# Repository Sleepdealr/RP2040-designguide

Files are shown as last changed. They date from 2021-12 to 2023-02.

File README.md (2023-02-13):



# Hardware design for the RP2040

This guide requires you to have prerequisite knowledge about PCB design and a little about the RP2040. This is not a guide for absolute beginners and should not be treated as one.

I have multiple tested and working boards using the RP2040, including an open source one you can find [here](https://github.com/Sleepdealr/RPAD)!

Bit of a disclaimer: I have mostly switched from RP2040 over to STM32F072 due to a few reasons. Mostly component cost and the amount of parts necessary, as well as overall stability. I have a tested and OSH f072 PCBs available on github. Namely [here](https://github.com/Sleepdealr/Majestouch-2-TKL-Replacement-Controller), [here](https://github.com/Sleepdealr/OSFRL), and [here](https://github.com/Sleepdealr/Kingsaver-Replacement-PCB). Designing with f072 is generally easier as well, so I would suggest it even for beginners.

## Contents

- [Hardware design for the RP2040](#hardware-design-for-the-rp2040)
  - [Contents](#contents)
  - [KiCad Version](#kicad-version)
  - [Libraries](#libraries)
  - [Extra Resources](#extra-resources)
  - [Schematic](#schematic)
    - [Component Choices](#component-choices)
      - [Voltage Regulator](#voltage-regulator)
      - [Crystal](#crystal)
      - [Flash](#flash)
      - [Pushbuttons](#pushbuttons)
  - [PCB](#pcb)
    - [Placement / Routing](#placement--routing)
    - [BOM](#bom)
  - [Firmware](#firmware)
    - [Flashing QMK on Linux from CLI](#flashing-qmk-on-linux-from-cli)
  - [Extra info](#extra-info)
    - [EEPROM](#eeprom)
  - [Too Complicated?](#too-complicated)

## KiCad Version

To open these files, you will need a recent stable version of KiCad (6.0 or later).

Stop using KiCad 5.X, it's out of date

## Libraries

You can either import them into your own library or keep them separate.

- Symbol:
  - Created by me to be easier to use
  - `/PCB/Libraries/Sleep-lib`
- Footprint:
  - Taken from Raspberry
  - `/PCB/Libraries/Footprints/RP2040-QFN-56.kicad_mod`
  - 3D Model is included

Images of the 3DView, EEschema, and PCBNew in the `/img` folder.

## Extra Resources

All the other information I found about the chip is in in the `/Pico-Resources` Folder

## Schematic

[PDF of schematic](PCB/RP2040-Guide.pdf)

THIS IMAGE WILL BE OUT OF DATE. LOOK AT THE PDF FOR THE LATEST VERSION.
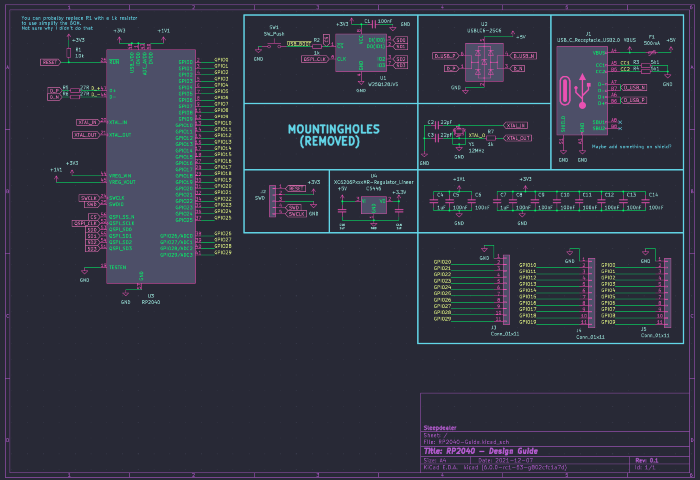
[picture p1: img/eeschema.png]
Schematic


If you want to know more about the components choices, read the section below or Raspberry's hardware design example.
The PDF is `/Pico-Resources/hardware-design-with-rp2040.pdf`.

I would also recommend reading my [Best practices for PCB Design](https://gist.github.com/Sleepdealr/ab05f5edb82eae9e0393f4d63da55adf) guide before making your own schematic or PCB

Breakout for SWD/GPIO is NOT required.

### Component Choices

Trust me on these pls

#### Voltage Regulator

Use the XC6206, it's a basic part on JLC. The 200mA it provides is plenty for the RP2040.

The AMS1117 has high quiescent current, needs large caps, and has a bad minimum load. Don't use it.

#### Crystal

C9002 is a great basic part for a 12MHz 3225 crystal

#### Flash

There are a ton of options for flash, but I tend to stick with C82317 as it's a basic part and has a good price. More than enough flash for any keyboard.

#### Pushbuttons

Although I didn't use a button on the included PCB files, you can easily add one yourself. A good cheap button that fits the Alps SKQG footprint is C318884.

####

## PCB

THIS IMAGE WILL BE OUT OF DATE. LOOK AT THE KiCad FILES FOR THE LATEST VERSION.
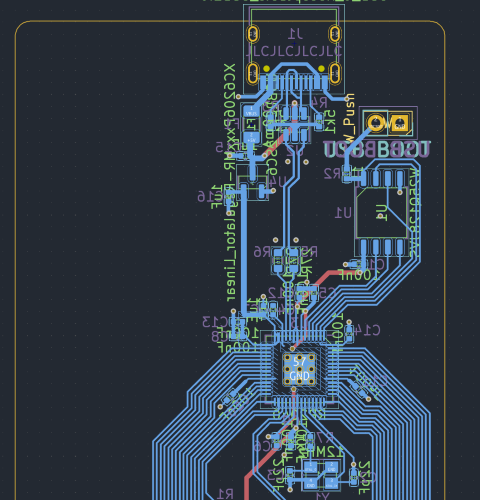
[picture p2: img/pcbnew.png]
PCB


### Placement / Routing

- Fills inside of the MCU were taken from the design example. You can just copy paste them out. Make sure to set the correct zone priority and clearances. Zones are filled from high to low numbers.
- Keep the decoupling capacitors close to their respective pins.
- Keep the flash and crystal as close as possible to the MCU with minimal overlaps and vias
  - If anything, just copy paste from my files
- I would suggest including an actual switch for USB BOOT or RESET on to make it easier to flash, but that's up to you.

### BOM

- Everything on the PCB can be assembled by JLC, all the part numbers have been added to the components with the Kicad JLCPCB plugin
- I have tested and working JLC part numbers for all of the components, but check the stock levels and prices first before ordering. There may be a better alternative available
- There are a few different flash sizes and packages to choose from. All of them should work pretty much the same, since firmware size is not an issue. I usually just go with the cheapest option

## Firmware

Both QMK and Vial have support for RP2040 in their master branches. Make sure to check the features you want before designing

- QMK
  - QMK Main Branch: <https://github.com/qmk/qmk_firmware/>
  - RP2040 available features: <https://docs.qmk.fm/#/platformdev_rp2040?id=raspberry-pi-rp2040>
- Vial
  - Vial Main Branch: <https://github.com/vial-kb/vial-qmk/>
- KMK
  - <https://github.com/KMKfw/kmk_firmware>
- Keyberon
  - <https://github.com/TeXitoi/keyberon>

To flash, hold the USB-BOOT button down as you plug in the keyboard (like Bootmagic reset)

### Flashing QMK on Linux from CLI

You will need to install picotool with your distro's package manager of choice, or [build it manually](https://github.com/raspberrypi/picotool#building).

In order to be able to flash properly, you will need to configure a custom udev rule.

Open a terminal and execute this script.

```bash
sudo mkdir -p /etc/udev/rules.d/
echo '# /etc/udev/rules.d/99-pico.rules

# Make an RP2040 in BOOTSEL mode writable by all users, so you can `picotool`
# without `sudo`.
SUBSYSTEM=="usb", ATTRS{idVendor}=="2e8a", ATTRS{idProduct}=="0003", MODE="0666"

# Symlink an RP2040 running MicroPython from /dev/pico.
#
# Then you can `mpr connect $(realpath /dev/pico)`.
SUBSYSTEM=="tty", ATTRS{idVendor}=="2e8a", ATTRS{idProduct}=="0005", SYMLINK+="pico"", TAG+="uaccess", TAG+="udev-acl"' | sudo tee /etc/udev/rules.d/99-pico.rules
sudo udevadm control --reload-rules
sudo udevadm trigger
```

Command borrowed from xyz's VIAL docs

## Extra info

### EEPROM

While the Raspberry Pi Pico RP2040 does not come with an EEPROM onboard, we simulate one by using a single 4K chunk of flash at the end of flash space.

**Note that this is a simulated EEPROM and will only support the number of writes as the onboard flash chip, not the 100,000 or so of a real EEPROM.** Therefore, do not frequently update the EEPROM or you may prematurely wear out the flash.

Source: <https://arduino-pico.readthedocs.io/en/latest/eeprom.html>

This isn't really an issue, as the flash chip I used is rated for 100k cycles [link to datasheet](https://www.winbond.com/resource-files/w25q128jv_dtr%20revc%2003272018%20plus.pdf)

## Too Complicated?

If all of this seems too daunting, my commissions are open! You can contact me on discord at Sleepdealer#0001 or through email at sleepdealer01@protonmail.com

Portfolio: <https://sleepdealer.xyz/article/portfolio>

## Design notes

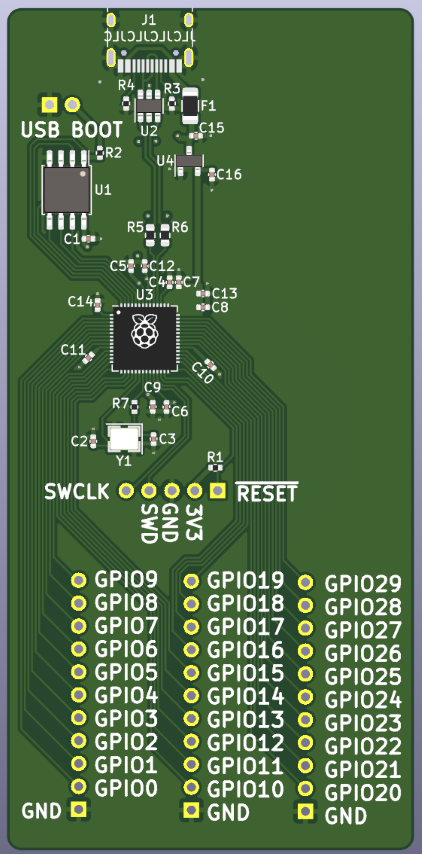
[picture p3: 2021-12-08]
img/render-board-back.png

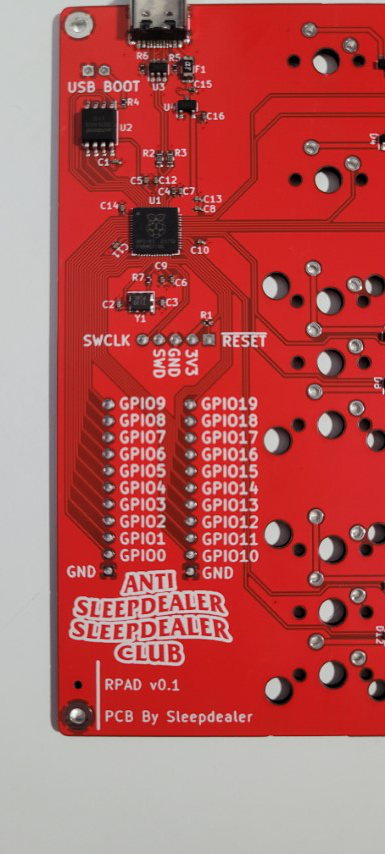
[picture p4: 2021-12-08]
img/RPAD.jpg

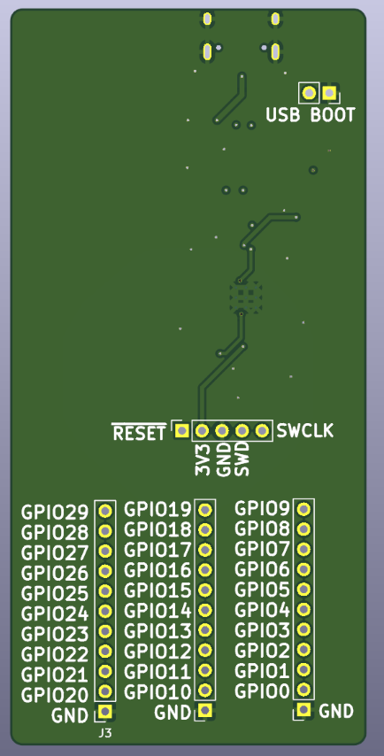
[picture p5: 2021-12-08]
img/render-board-front.png

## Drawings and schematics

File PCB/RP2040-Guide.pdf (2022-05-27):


1 GPIO8 11 GPIO9 12 GPIO10 13 GPIO11 14 GPIO12 15 GPIO13 16 GPIO14 17 GPIO15 18 TESTEN 19 GPIO0 2 XTAL_IN 20 XTAL_OUT 21 SWCLK 24 SWDIO 25 ~{RUN} 26 GPIO16 27 GPIO17 28 GPIO18 29 GPIO1 3 GPIO19 30 GPIO20 31 GPIO21 32 GPIO22 34 GPIO23 35 GPIO24 36 GPIO25 37 GPIO26/ADC0 38 GPIO27/ADC1 39 GPIO2 4 GPIO28/ADC2 40 GPIO29/ADC3 41 ADC_AVDD 43 VREG_VIN 44 VREG_VOUT 45 D- 46 D+ 47 USB_VDD 48 GPIO3 5 DVDD 50 QSPI_SD3 51 QSPI_SCLK 52 QSPI_SD0 53 QSPI_SD2 54 QSPI_SD1 55 QSPI_SS_N 56 GND 57 GPIO4 6 GPIO5 7 GPIO6 8 GPIO7 9 U3 GND RP2040 +3.3V C6

File: RP2040-Guide.kicad_sch Sheet: / Sleepdealer

Id: 1/1 Title: RP2040 - Design Guide

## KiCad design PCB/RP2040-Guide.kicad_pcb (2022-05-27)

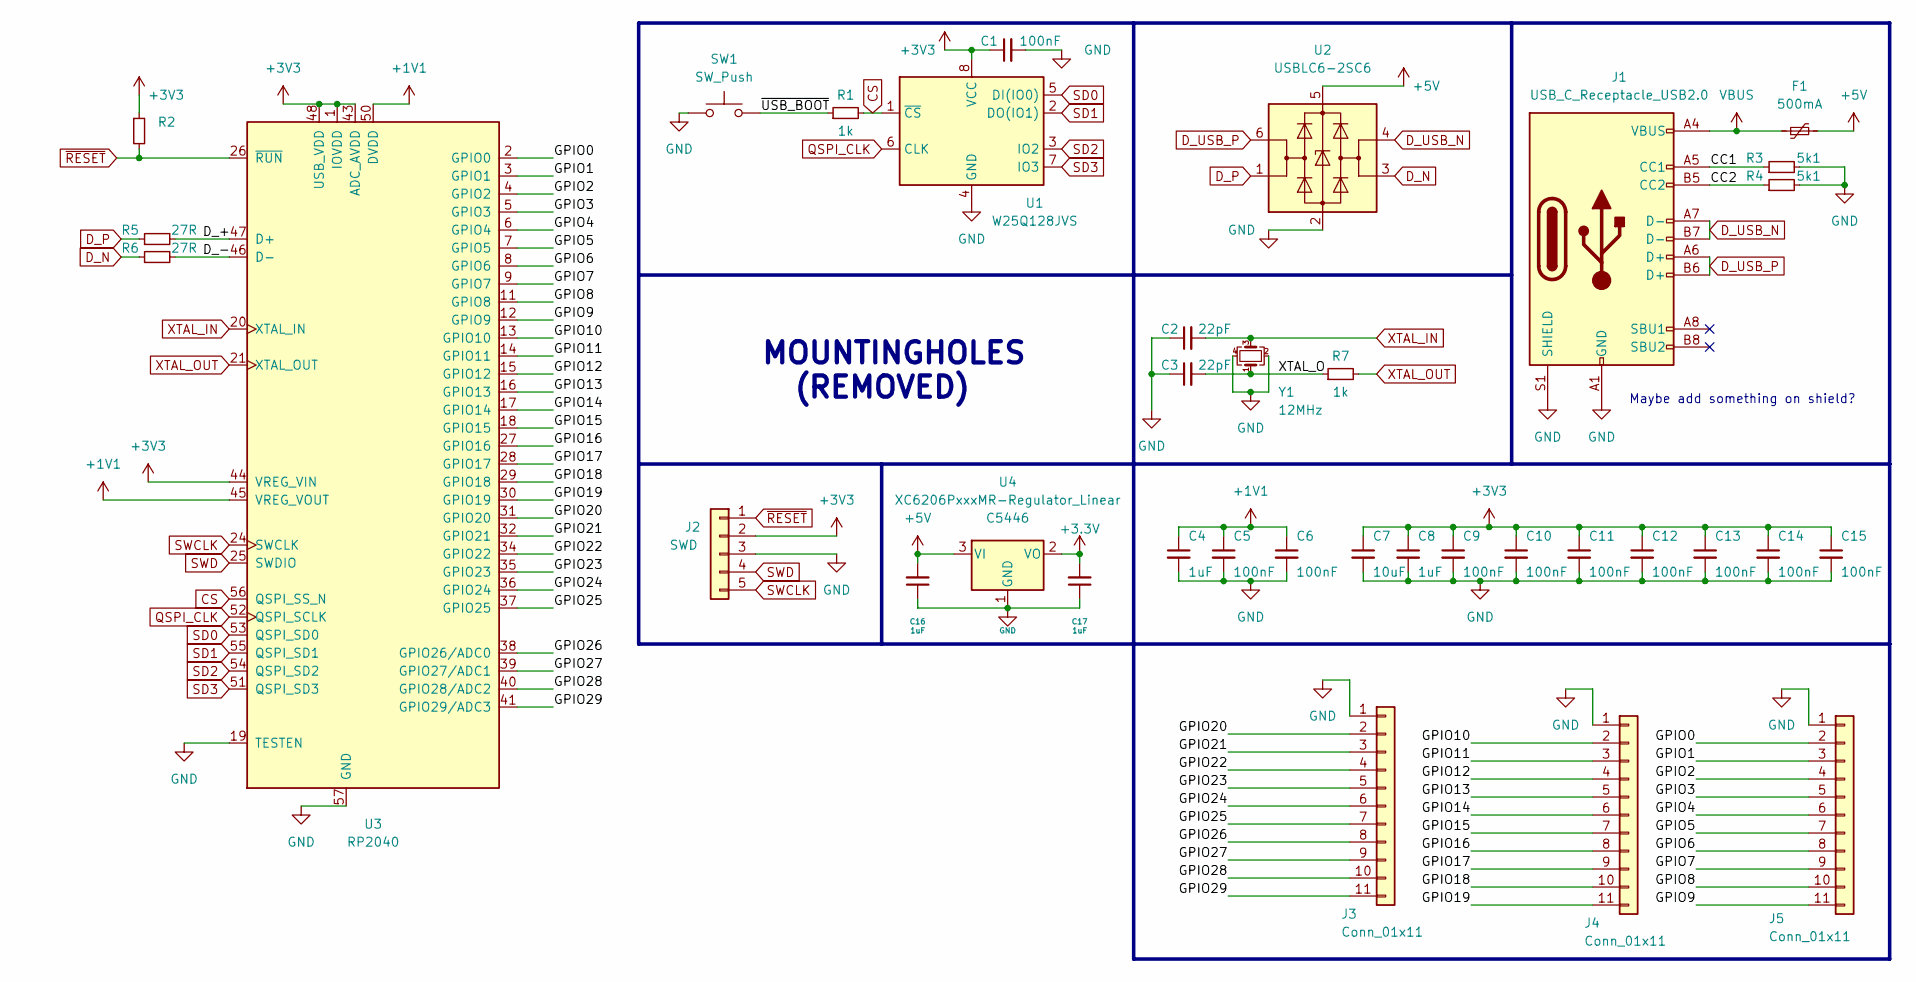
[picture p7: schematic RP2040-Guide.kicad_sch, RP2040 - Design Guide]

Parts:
C1, C5, C6, C9, C10, C11, C12, C13, C14, C15: 100nF; C_0402_1005Metric; LCSC C1525
C2, C3: 22pF; C_0402_1005Metric; LCSC C1555
C4, C8, C16, C17: 1uF; C_0402_1005Metric; LCSC C52923
C7: 10uF; C_0402_1005Metric; LCSC C15525
F1: 500mA; Fuse_1206_3216Metric; LCSC C70076
J1: USB_C_Receptacle_USB2.0; USB_C_Receptacle_HRO_TYPE-C-31-M-12; LCSC C165948
J2: SWD; PinSocket_1x05_P2.54mm_Vertical
J3, J4, J5: Conn_01x11; PinSocket_1x11_P2.54mm_Vertical
R1, R7: 1k; R_0402_1005Metric; LCSC C11702
R2: LCSC C11702
R3, R4: 5k1; R_0402_1005Metric; LCSC C25905
R5, R6: 27R; R_0603_1608Metric; LCSC C25190
SW1: SW_Push; PinSocket_1x02_P2.54mm_Vertical
U1: W25Q128JVS; SOIC-8_5.23x5.23mm_P1.27mm; LCSC C131025
U2: USBLC6-2SC6; SOT-23-6; LCSC C2827654
U3: RP2040; RP2040-QFN-56; LCSC C2040
U4: XC6206PxxxMR-Regulator_Linear; SOT-23; LCSC C5446
Y1: 12MHz; Crystal_SMD_3225-4Pin_3.2x2.5mm; LCSC C9002

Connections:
+1V1: C4.1, C5.1, C6.1, U3.23 (DVDD), U3.45 (VREG_VOUT), U3.50 (DVDD)
+5V: C16.2, F1.2, U2.5 (VBUS), U4.3 (VI)
/CC1: J1.A5 (CC1), R3.1
/CC2: J1.B5 (CC2), R4.1
/D_+: R5.2, U3.47 (D+)
/D_-: R6.2, U3.46 (D-)
/GPIO0: J5.2, U3.2 (GPIO0)
/GPIO1: J5.3, U3.3 (GPIO1)
/GPIO2: J5.4, U3.4 (GPIO2)
/GPIO3: J5.5, U3.5 (GPIO3)
/GPIO4: J5.6, U3.6 (GPIO4)
/GPIO5: J5.7, U3.7 (GPIO5)
/GPIO6: J5.8, U3.8 (GPIO6)
/GPIO7: J5.9, U3.9 (GPIO7)
/GPIO8: J5.10, U3.11 (GPIO8)
/GPIO9: J5.11, U3.12 (GPIO9)
/GPIO10: J4.2, U3.13 (GPIO10)
/GPIO11: J4.3, U3.14 (GPIO11)
/GPIO12: J4.4, U3.15 (GPIO12)
/GPIO13: J4.5, U3.16 (GPIO13)
/GPIO14: J4.6, U3.17 (GPIO14)
/GPIO15: J4.7, U3.18 (GPIO15)
/GPIO16: J4.8, U3.27 (GPIO16)
/GPIO17: J4.9, U3.28 (GPIO17)
/GPIO18: J4.10, U3.29 (GPIO18)
/GPIO19: J4.11, U3.30 (GPIO19)
/GPIO20: J3.2, U3.31 (GPIO20)
/GPIO21: J3.3, U3.32 (GPIO21)
/GPIO22: J3.4, U3.34 (GPIO22)
/GPIO23: J3.5, U3.35 (GPIO23)
/GPIO24: J3.6, U3.36 (GPIO24)
/GPIO25: J3.7, U3.37 (GPIO25)
/GPIO26: J3.8, U3.38 (GPIO26/ADC0)
/GPIO27: J3.9, U3.39 (GPIO27/ADC1)
/GPIO28: J3.10, U3.40 (GPIO28/ADC2)
/GPIO29: J3.11, U3.41 (GPIO29/ADC3)
/XTAL_O: C3.2, R7.1, Y1.1
/~USB_BOOT: R1.1, SW1.2
CS: R1.2, U1.1 (~CS), U3.56 (QSPI_SS_N)
D_N: R6.1, U2.3 (I/O2)
D_P: R5.1, U2.1 (I/O1)
D_USB_N: J1.A7 (D-), J1.B7 (D-), U2.4 (I/O2)
D_USB_P: J1.A6 (D+), J1.B6 (D+), U2.6 (I/O1)
GND: C1.2, C2.1, C3.1, C4.2, C5.2, C6.2, C7.2, C8.2, C9.2, C10.2, C11.2, C12.2, C13.2, C14.2, C15.2, C16.1, C17.1, J1.A1 (GND), J1.A12 (GND), J1.B1 (GND), J1.B12 (GND), J1.S1 (SHIELD), J2.3, J3.1, J4.1, J5.1, R3.2, R4.2, SW1.1, U1.4 (GND), U2.2 (GND), U3.19 (TESTEN), U3.57 (GND), U4.1 (GND), Y1.2, Y1.4
QSPI_CLK: U1.6 (CLK), U3.52 (QSPI_SCLK)
SD0: U1.5 (DI(IO0)), U3.53 (QSPI_SD0)
SD1: U1.2 (DO(IO1)), U3.55 (QSPI_SD1)
SD2: U1.3 (IO2), U3.54 (QSPI_SD2)
SD3: U1.7 (IO3), U3.51 (QSPI_SD3)
SWCLK: J2.5, U3.24 (SWCLK)
SWD: J2.4, U3.25 (SWDIO)
VBUS: F1.1, J1.A4 (VBUS), J1.A9 (VBUS), J1.B4 (VBUS), J1.B9 (VBUS)
XTAL_IN: C2.2, U3.20 (XTAL_IN), Y1.3
XTAL_OUT: R7.2, U3.21 (XTAL_OUT)
~RESET: J2.1, R2.2, U3.26 (~RUN)

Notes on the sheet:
MOUNTINGHOLES (REMOVED)
Maybe add something on shield?

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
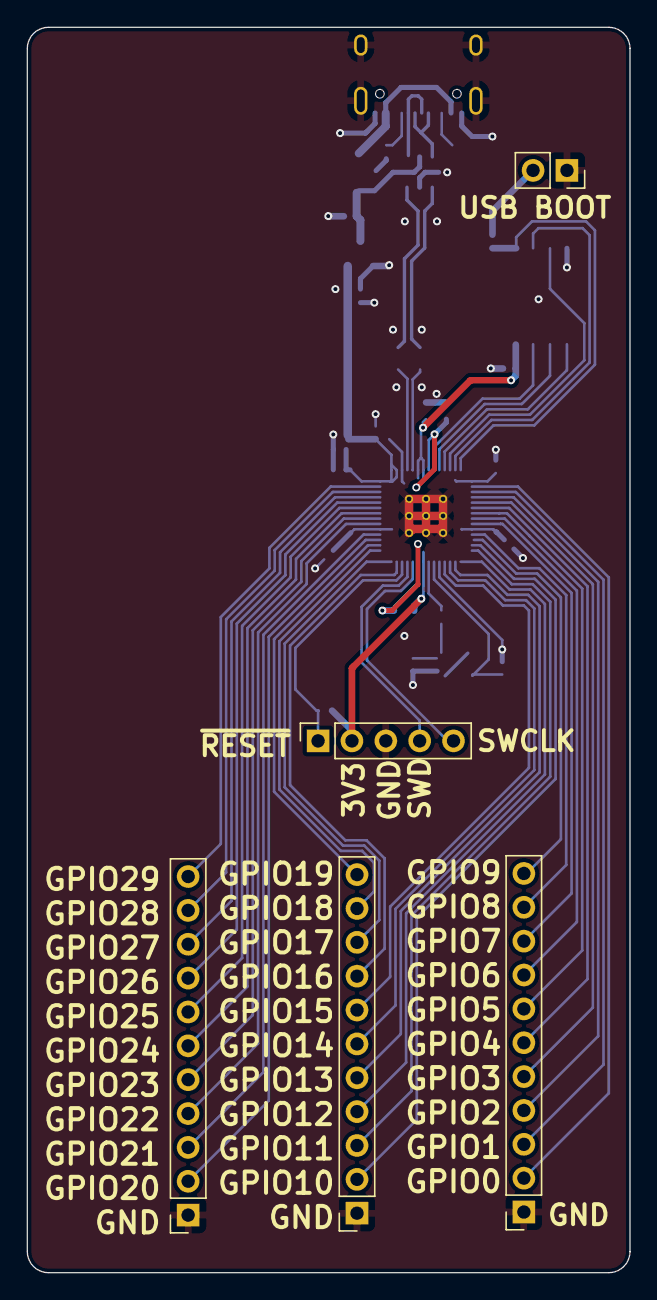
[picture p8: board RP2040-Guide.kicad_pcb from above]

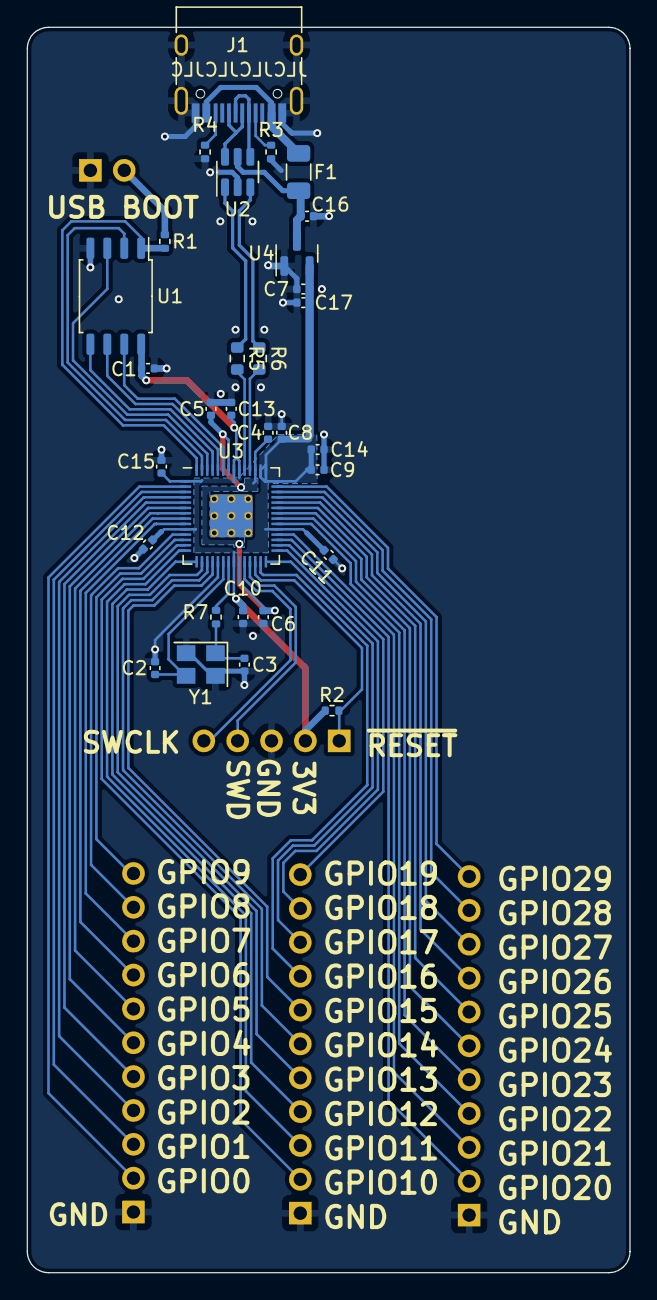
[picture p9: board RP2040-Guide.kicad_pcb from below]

Board: 2 copper layers, 45.2 x 93.4 mm, 36 parts (31 on the bottom side), 56 nets.

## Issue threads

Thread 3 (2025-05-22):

Slow oscillator

harbaum, 2025-05-22:
The oscillator you link to seem to be one of the "slow" ones as described at https://github.com/raspberrypi/pico-sdk/pull/457

Following the solutions there makes the board work reliably. You might add a hint for this somewhere prominent. I was initially puzzled by the fact that my board would show up on USB, but would then not boot the installed firmware after a power up.

And thanks for the design, I am using this as a base for https://github.com/harbaum/MiSTeryNano/tree/main/board/misteryshield20k_lite

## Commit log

2021-12-08 Edit formatting on readme/pcb/schematic
    [RP2040-Guide.kicad_pcb, RP2040-Guide.kicad_sch]
2021-12-26 Update guide (Thanks xyz!)
    [RP2040-Guide.kicad_pcb, RP2040-Guide.kicad_sch]
2022-03-13 Update BOM and borked vias (Thanks to SpeedyPotato!)
    [RP2040-Guide.kicad_pcb, RP2040-Guide.kicad_sch]
2022-05-27 Update guide a bit
    [RP2040-Guide.kicad_pcb, RP2040-Guide.kicad_sch]
